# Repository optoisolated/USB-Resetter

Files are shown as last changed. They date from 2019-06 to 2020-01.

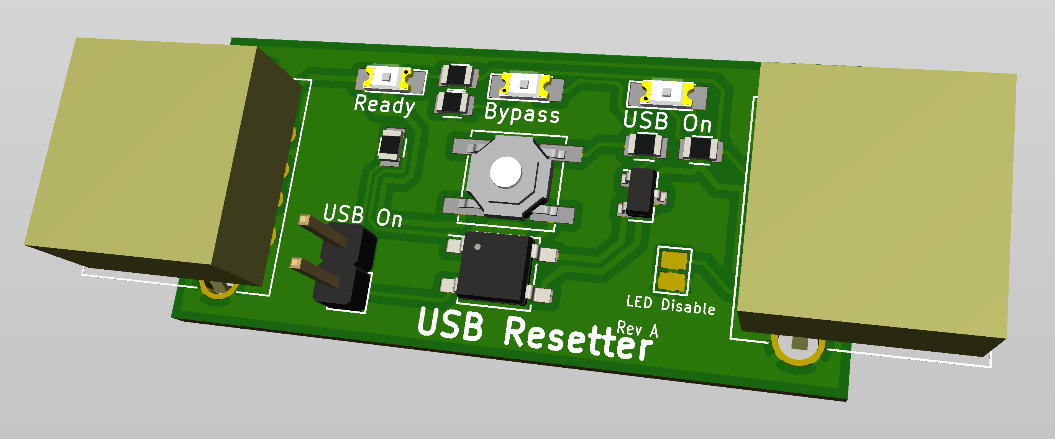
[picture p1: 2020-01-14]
USBResetter-3DView.png

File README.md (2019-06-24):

# USB Resetter

The USB Resetter allows for using a 5V power source such as a GPIO Pin on a Raspberry Pi or Arduino to enable/disable a USB A connection. This was designed to facilitate allowing my Raspberry Pi to Reset my Fine Offset Weather Station which suffers from USB Lockup, and the only recourse is to forcibly power-cycle the device. 

This device uses a Male and Female USB-A connection to allow for simple installation, and then a 2 PIN GPIO-Compatible input for the reset. The circuit is normally open, so requires power to enable the USB. The device only switches the VBUS Pin on the USB device, so the data pins are not hindered in any way by active circuitry; which may reduce throughput.

The Power Switching circuit uses an optically isolated Solid State Relay to minimise power loss and ensure a clean power transition. The on/off pins directly connect to the LED side of the Optocoupler and are not driven in any way by the USB power line. This ensures no power loss due to the optoisolator LED and also ensures no shared ground between the the USB line and the device performing the switching. 

The ASSR-1218 SSR has been assumed to be run between 3.3v and 5v and has as an in-series resistor to accomodate that. The line can be driven with a higher voltage but will need an appropriate voltage divider and circuit protection. The SSR will draw between 2mA and 20mA in normal operation. The on/off pins are not latched, so need to driven to remain on.

The Bypass switch is driven by the VBUS line and does not need any external power connected in order to work. 

Note that with the Bypass switch in the on position, the On/Off pins will have no effect.

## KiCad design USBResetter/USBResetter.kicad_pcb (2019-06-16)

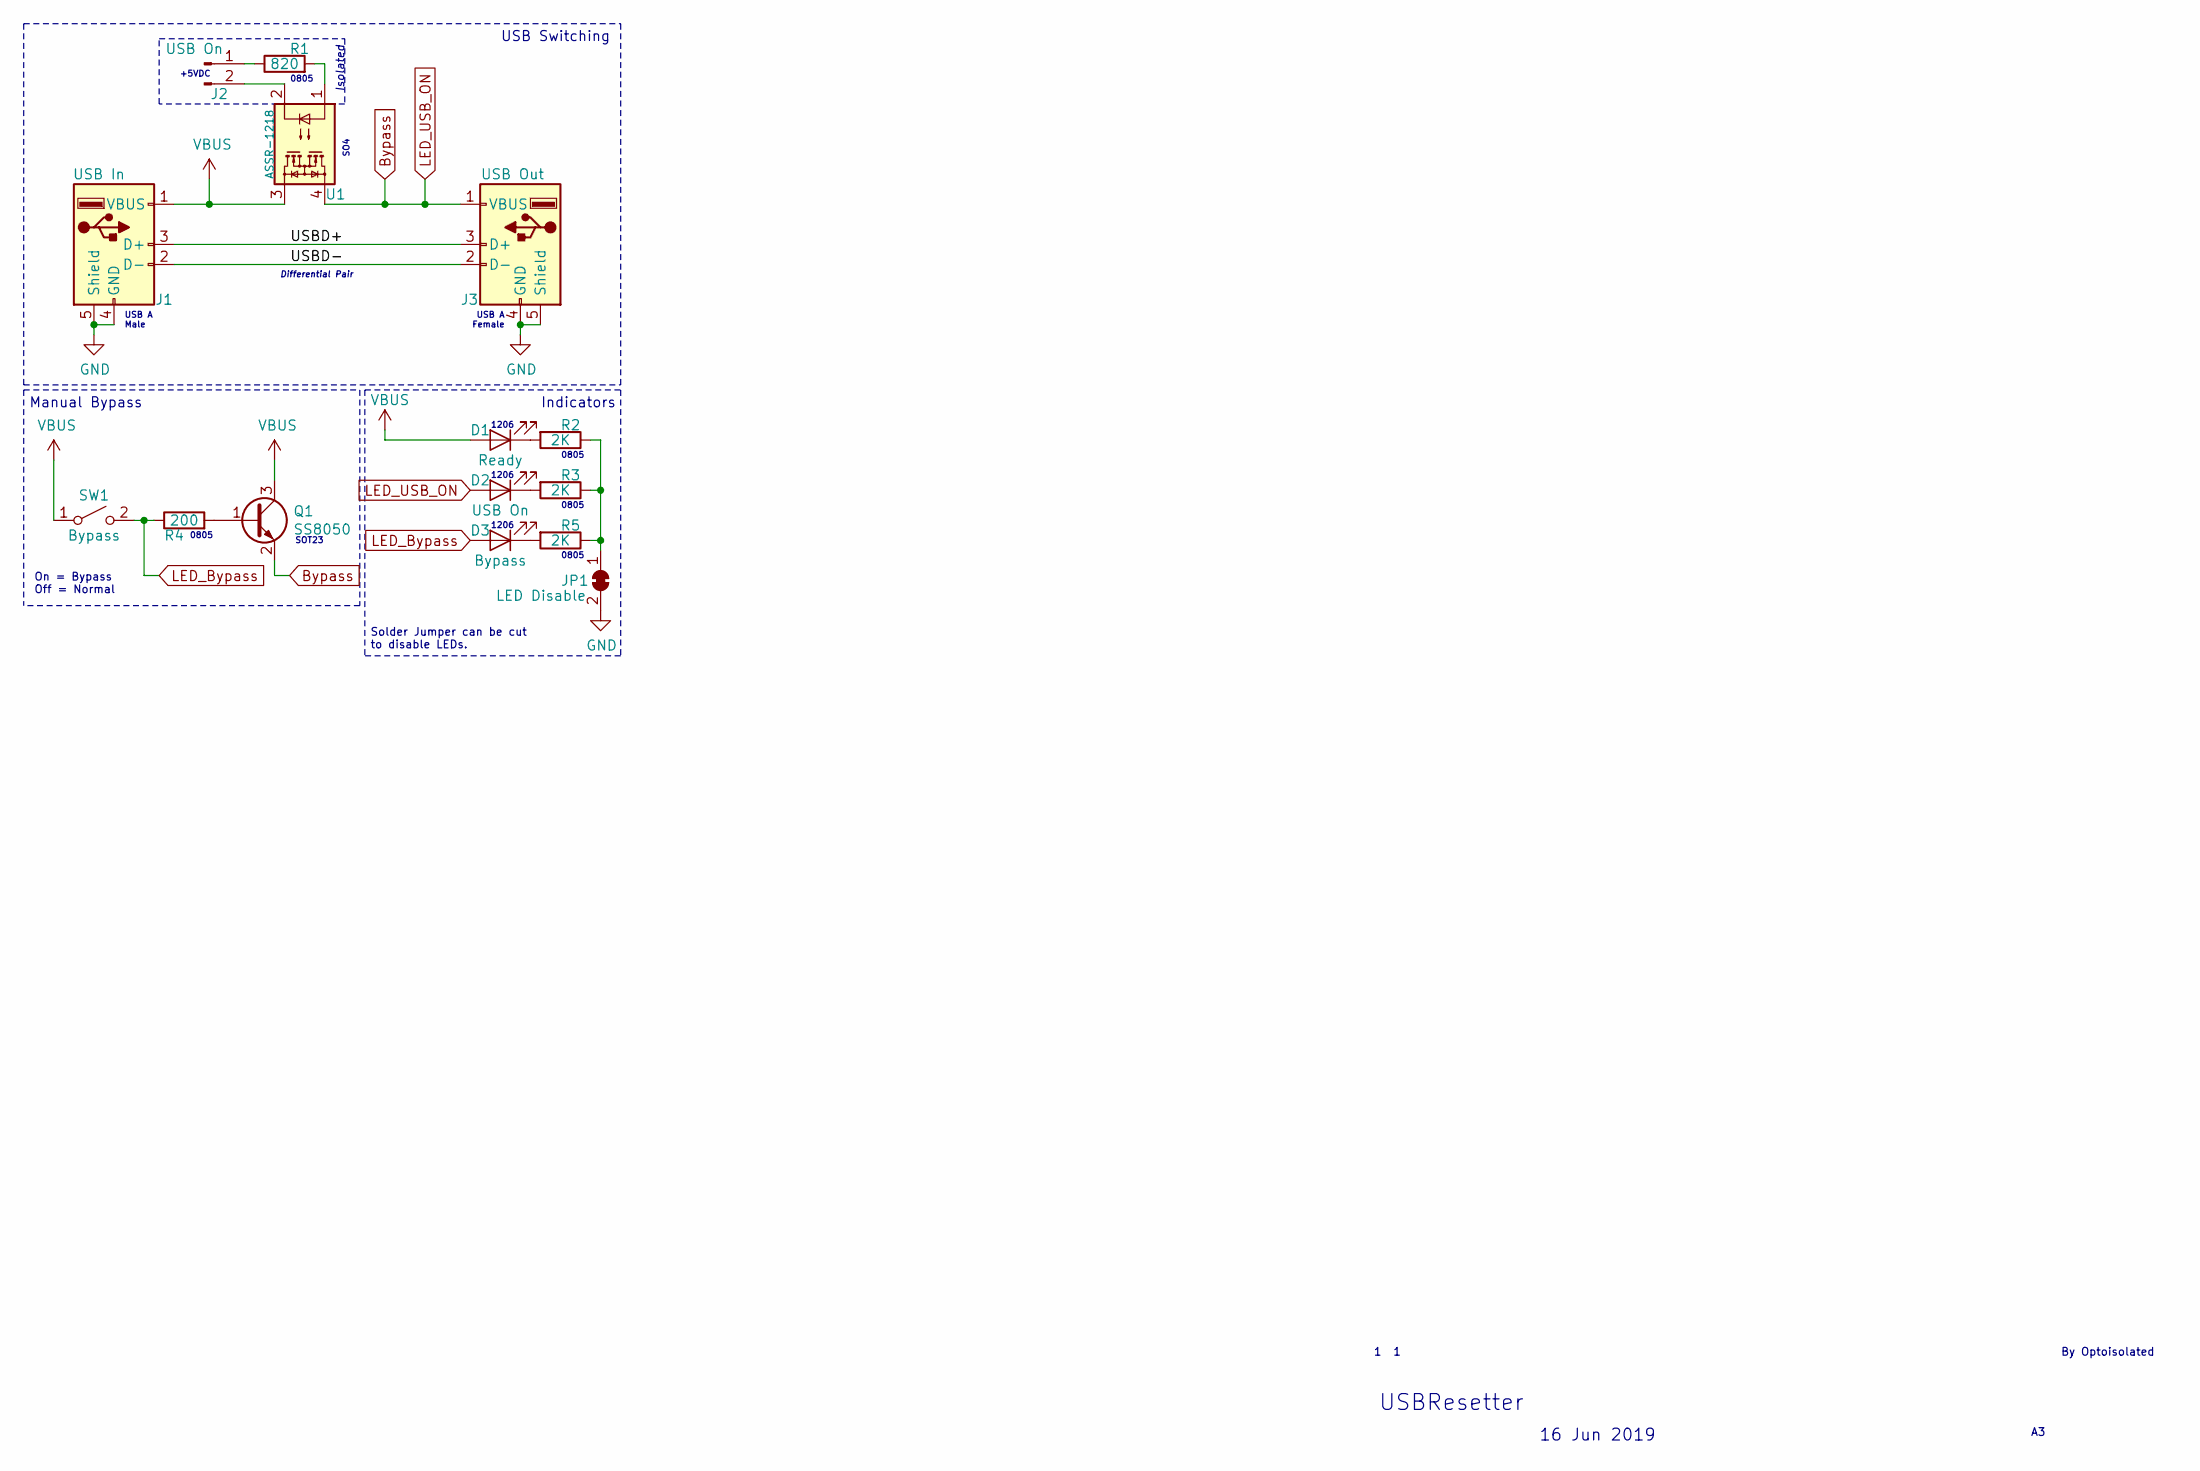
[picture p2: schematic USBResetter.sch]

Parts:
D1: Ready; LED_1206
D2: USB On; LED_1206
D3: Bypass; LED_1206
J1: USB In; USB_A
J2: USB On; Pin_Header_Straight_1x02_Pitch2.54mm
J3: USB Out; USB_A
JP1: LED Disable; SolderJumper-2_P1.3mm_Bridged_Pad1.0x1.5mm
Q1: SS8050; SOT-23
R1: 820; R_0805
R2, R3, R5: 2K; R_0805
R4: 200; R_0805
SW1: Bypass; SW_SPST_EVPBF
U1: ASSR-1218; SO-4_4.4x4.3mm_Pitch2.54mm

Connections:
/USBD+: J1.3 (D+), J3.3 (D+)
/USBD-: J1.2 (D-), J3.2 (D-)
Bypass: D2.2 (A), J3.1 (VBUS), Q1.2 (E), U1.4
GND: J1.4 (GND), J1.5 (Shield), J3.4 (GND), J3.5 (Shield), JP1.2 (B)
LED_Bypass: D3.2 (A), R4.1, SW1.2 (B)
unnamed: D1.1 (K), R2.2
unnamed: D2.1 (K), R3.2
unnamed: D3.1 (K), R5.2
unnamed: J2.1, R1.1
unnamed: J2.2, U1.2
unnamed: JP1.1 (A), R2.1, R3.1, R5.1
unnamed: Q1.1 (B), R4.2
unnamed: R1.2, U1.1
VBUS: D1.2 (A), J1.1 (VBUS), Q1.3 (C), SW1.1 (A), U1.3

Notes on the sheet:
+5VDC
USB Switching
Manual Bypass
Indicators
Isolated
Solder Jumper can be cut to disable LEDs.
USBResetter
16 Jun 2019
1 1
By Optoisolated
On = Bypass Off = Normal
Differential Pair
SOT23
1206
USB A Male
USB A Female
SO4
0805

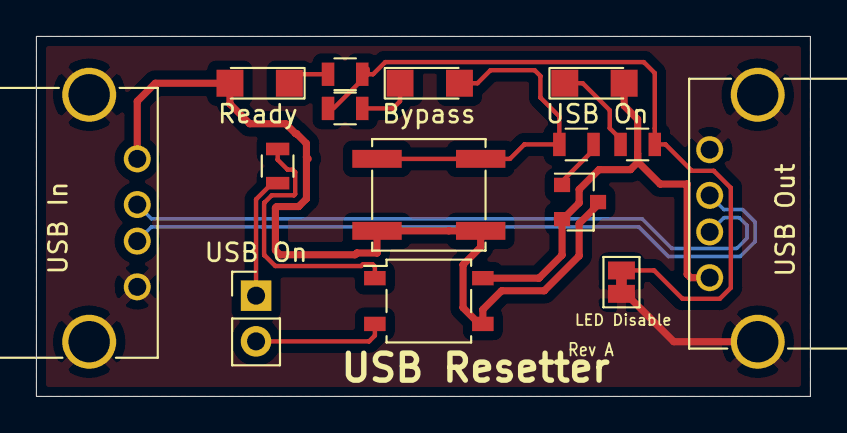
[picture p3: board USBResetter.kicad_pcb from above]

Board: 2 copper layers, 43.0 x 20.0 mm, 15 parts (0 on the bottom side), 14 nets.

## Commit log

2019-06-14 Layout Formatting
    General layout tidy up.
    [USBResetter.sch]
2019-06-14 PCB Layout, Parts Assignment
    [USBResetter.kicad_pcb, USBResetter.sch]
2019-06-14 Fixed issues with components and layout
    Replaced Footprint for NPN Transistor to match the Pinout of the Part. Recreated the Data lines using Differential Pair to ensure optimal USB Data speed and minimal interference.
    [USBResetter.kicad_pcb, USBResetter.sch]
2019-06-14 Generated Gerber Files for Fabrication
    [USBResetter-B_Cu.gbr, USBResetter-B_Mask.gbr, USBResetter-B_Paste.gbr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]
2019-06-14 Rev A (#1)
    * Update README.md
    * Update README.md
    * Layout Formatting
    * PCB Layout, Parts Assignment
    * Fixed issues with components and layout
    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
    [USBResetter.kicad_pcb, USBResetter.sch]
2019-06-14 Dev (#2)
    * Generated Gerber Files for Fabrication
    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
    [USBResetter-B_Cu.gbr, USBResetter-B_Mask.gbr, USBResetter-B_Paste.gbr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]
2019-06-15 Fixed Bypass Transistor issue
    Removed current limiting resistor and connection to ground for the Bypass Transistor, to allow it to work as intended.
    [USBResetter.kicad_pcb, USBResetter.sch]
2019-06-15 Recreated Rev A Gerbers with Fixes
    Removed CL Resistor on Bypass circuit; Fixed Transister Grounding issue.
    [USBResetter-B_Cu.gbr, USBResetter-B_Mask.gbr, USBResetter-B_Paste.gbr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]
2019-06-15 Removed Gerbers
    [USBResetter-B_Cu.gbr, USBResetter-B_Mask.gbr, USBResetter-B_Paste.gbr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]
2019-06-15 Fixed board dimensions issue (#5)
    Found one edge was short by 0.2mm.
    [USBResetter.kicad_pcb]
2019-06-15 Board Dimension issue resolved. (#6)
    * Fixed Board Dimension issue
    * Board outline wasn't rendering correctly. Recreated the Edge Cuts layer
    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
    [USBResetter.kicad_pcb]
2019-06-16 Last Revision A update. (#7)
    Fixed board dimensions issue
    * Found one edge was short by 0.2mm.
    Bypass LED, Button Centered
    * Added Bypass LED Indicator LED.
    * Moved the Bypass button to center of the board.
    * Simpliflied the ground plane.
    Properly annotated schematic
    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
    [USBResetter.kicad_pcb, USBResetter.sch]
2019-06-16 Timing Update (#8)
    Board outline wasn't rendering correctly. Recreated the Edge Cuts layer
    * Bypass LED, Button Centered
    Layout Update
    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
    [USBResetter.kicad_pcb]
2020-01-14 Added 3D Render of PCB
